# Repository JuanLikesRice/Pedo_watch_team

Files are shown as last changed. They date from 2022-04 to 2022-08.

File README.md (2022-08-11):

# Pedo_watch_team
Final for Elec327 code for MSP430

Website explaining our Design: https://olr148.wixsite.com/pedowatchteam/

DataSHeets for the pedometer sensor:
https://download.mikroe.com/documents/datasheets/KX126-1063.pdf
https://kionixfs.azureedge.net/en/document/AN073-Getting-Started-with-Pedometer.pdf

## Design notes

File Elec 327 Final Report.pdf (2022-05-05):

## Pedo-Watch: Final Project Written Report

By: Juan Garza, Son Nguyen, Oscar Reynozo

ELEC 327

Due: May 4, 2022

Professor Kemere

Design Concept:

We sought to design a simple energy-efficient electronic pedometer popularly used

among fitness and health enthusiasts. For our final project design, we introduce the Pedo-Watch.

Our watch utilizes the interrupt and SPI configuration capabilities of the MSP430G2553

microcontroller to detect and display the user’s number of steps. In addition, we incorporated a

pedometer three-click sensor to see the number of steps the person has taken and a color TFT

screen to display the time of the day and the number of steps that the user has taken.

Additionally, we implemented two-button functionality to be able to reset or set the step count

and current time.

Bill of Materials:

- Texas Instruments Launchpad
- 20-pin MSP430G2553
- Datasheet: https://elec327.github.io/assets/documents/msp430g2553.pdf
- Adafruit 1.14” 240x135 color screen with the ST7789VW TFT driver
- Link: https://www.adafruit.com/product/4383
- Datasheet:

https://cdn-learn.adafruit.com/assets/assets/000/082/882/original/ST7789VW_SP

EC_V1.0.pdf?1571860977

- Pedometer 3-Click Sensor
- Link: https://www.mikroe.com/pedometer-3-click
- Datasheet: https://download.mikroe.com/documents/datasheets/KX126-1063.pdf
- Two buttons
- Two 1k Ohm resistors
- 100k Ohm resistor
- 4.7k Ohm resistor
- Two 47nF capacitors
- Two 0.1uF capacitors

SPI Configuration:

Generally, our Pedo-Watch works by configuring the KX126-1063 IC, our pedometer

three-click sensor, and the Adafruit 1.14” 240x135 color screen with the ST7789VW TFT driver,

our color TFT display. We decided to use the SPI interface because our pedometer and screen

require a high-speed clock to check and update the number of steps taken and the current time.

For our SPI configuration, the MSP430G2553 serves as the master device. Meanwhile, the

screen and pedometer serve as slave devices. With the exception of the pedometer, each slave

device usually has a dedicated chip select pin connection to the MSP430G2553 to determine the

slave device that the MSP430G2553 is writing to at any given time. In this case, when providing

input or receiving an output from a device, the MOSI (Master-out, Slave-in) and MISO

(Master-in, Slave-out) configurations determine the direction in that information is being read or

written.

Pedometer Configuration and Implementation:

With the KX126-1063's SPI configuration, we utilized a 0.5 MHz clock signal to

determine whether to read or write at every positive edge of the clock signal. When given a read

or write command at every positive edge of the clock signal, the command must modify the IC's

registers to access settings specified by the chip's datasheet. The MSP430G2553 must first set

the pedometer to software reset mode, which requires control register one and control register 2

to be changed. Once in software reset, the sensor can be configured into a pedometer function

and count steps. The KX126-1063 IC can function as both a pedometer and an accelerometer.

Under the pedometer configuration mode, the acceleration register has access to ten different

control registers PED_CNTL_XX; these control how the pedometer counts steps, including the

threshold for calculating steps. In addition, there are two 8-bits registers used to represent the

step count, one register corresponding to the high values (8 most significant bits of steps) and

another register corresponding to the low values (8 least important bits of the step count). When

the displacement reaches a certain threshold where the sensor accelerates and decelerates from

the threshold value, a step is detected, and the step counter increments. In addition, there are

configurations for the interrupt pin; these can set pins to be active or low for when the pedometer

counts above a threshold of steps.

TFT Screen Configuration and Implementation:

Moreover, the TFT screen's SPI configuration works similarly to the KX126-1063's SPI

configuration. However, we configured it with a 1 MHz clock signal for writing or reading data

at the positive edge of each clock cycle. To set up the TFT screen, we must first initialize a

software reset, then configure the master, phase, and synchronous modes in the specified order

by sending commands specified in the datasheet and modifying the TFT screen's control

registers. Once the TFT screen can receive bytes for displaying text, the CASET and RASET

commands must be used to specify the row and column when drawing a pixel. The RAMWR

(for writing to the RAM) command writes its corresponding byte value to the UCB0TXIFG

buffer, and a byte indicates the pixel's color. Thus, to write messages to the screen, each pixel in

the screen must be iterated through and colored appropriately to form text on the screen with a

specific text font and color. Utilizing this framework for writing text onto the TFT screen, we

used a custom font for a microcontroller and itoa function in C to convert the current number of

steps and time from an integer to a string displayed onto the TFT screen as the values update.

Once the screen successfully updates the number of steps and time as part of our minimally

viable product, we incorporate animations with color changes and transitions to make the TFT

screen more appealing and entertaining. Unlike the step counter, the time counter continuously

incremented every second and timed appropriately using an interrupt delay.

Buttons Implementation and FSM:

The last component of the system implemented was the two buttons' active low

functionality. These buttons operate in a finite state machine. The initial state is displaying,

where the top button corresponds to reading the step registers and updating the count if there are

steps stored in the sensor. The bottom button corresponds to resetting the step count to zero.

When both buttons are pressed simultaneously, the TFT display is set to a time-setting state. The

top button increments the hour value of the current time, and pressing the bottom button minute

value of the current time. Conditionals in the code ensure that decreasing the time does not go

below 00:00 and increasing the time does not go above 23:59. Once in time-setting mode, the

user can leave the time-setting mode and set the time chosen by pressing both buttons at the

same time again. A state machine diagram is drawn below.

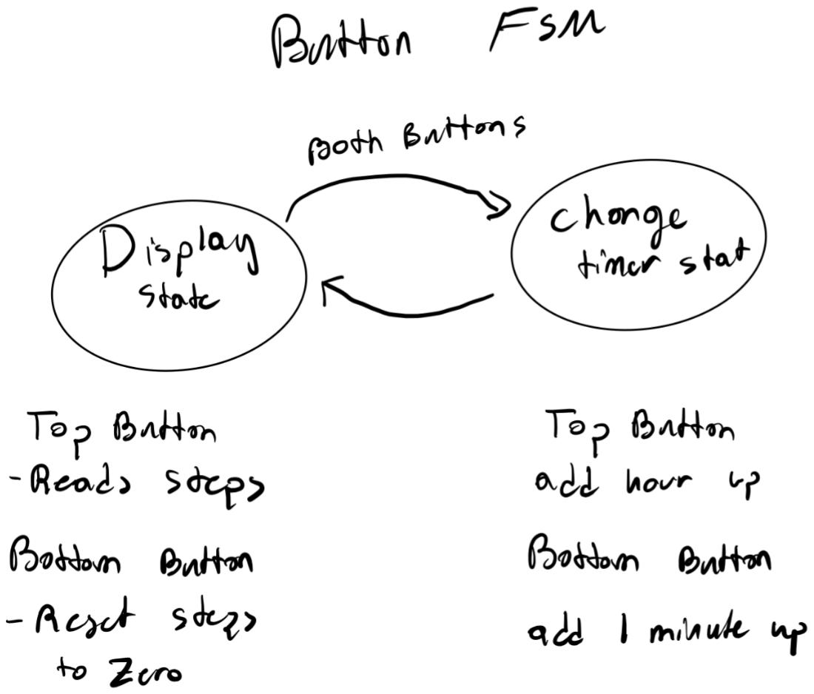
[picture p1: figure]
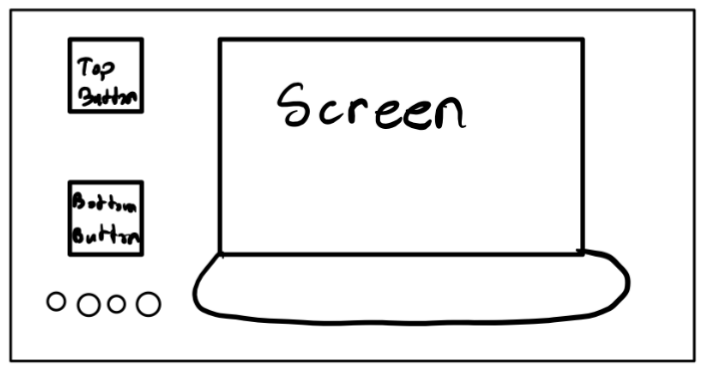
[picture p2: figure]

PCB Design:

For our PCB design, aside from including the MSP430G2553, the KX126-1063, the

display’s pins, and the buttons, we also had the 4-pins (GND, VDD, RST, and TEST) connecting

to the launchpad for uploading code and resistors/capacitors needed for some of the pedometer

and button connections. Here below are images of our Eagle PCB schematic and board files:

Eagle PCB Schematic File

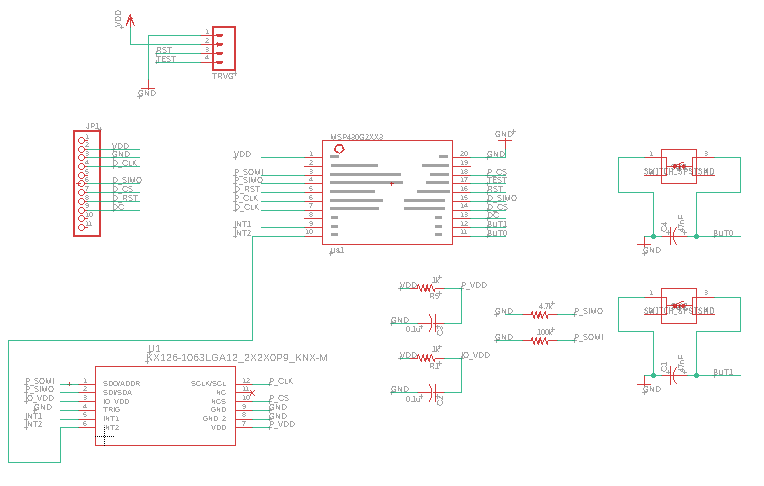
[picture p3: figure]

The 47 nF capacitors connected to the buttons eliminate noise and ensure a smooth

transition from high to low. Further, the 1k ohm resistor and 0.1 uF capacitor voltage dividers

supply 2.2 V to the KX126-1063 chip. Lastly, the 4.7k ohm and 100k ohm resistors reduce the

noise in the data transmitted from SDO and SDI pins in the KX126-1063 chip.

Eagle PCB Board File

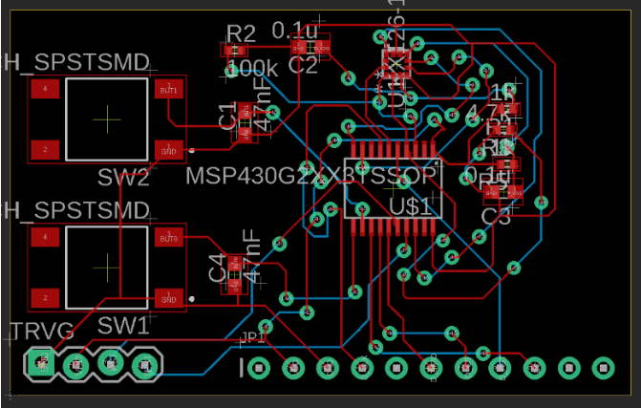
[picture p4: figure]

Only the DVCC and DVSS pins of the microcontroller are shared among the different

components of the PCB to supply voltage and ground. Except for the vacant pins P1.0, P2.0, and

P2.6, the rest of the microcontroller’s pins are allocated to a specific purpose for a single

component. Lastly, for reference, here are the pin layouts for the 20-pin MSP430G2553

microcontroller and KX126-1063 IC, along with each pin’s use:

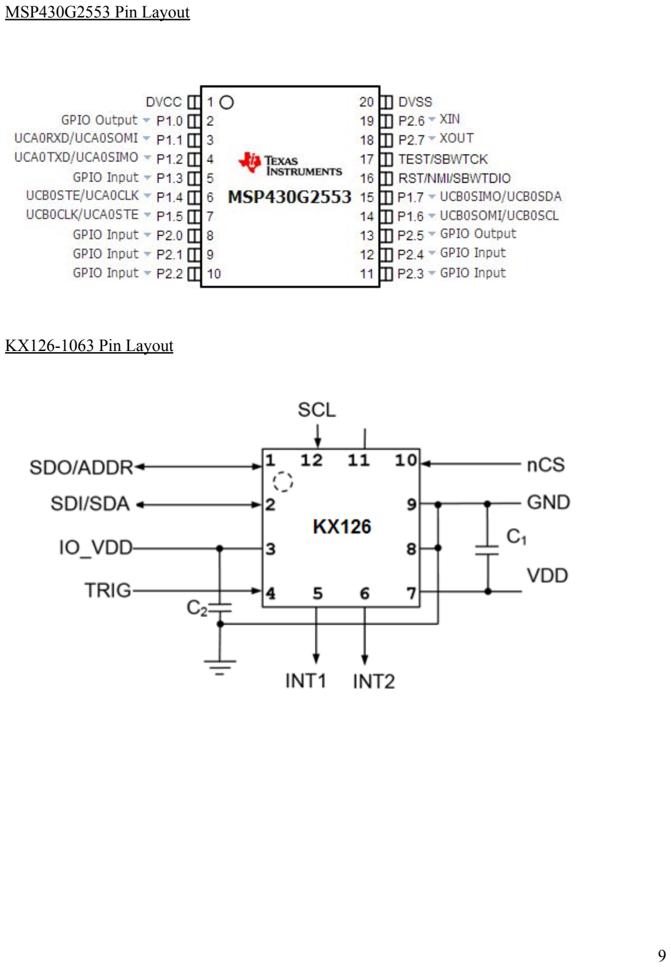
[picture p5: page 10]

MSP430G2553 Pin Layout

KX126-1063 Pin Layout

Low-Power Implementation:

We achieved our goal of making the Pedo-Watch a low-power system by extensively

utilizing interrupts throughout our system when awaiting inputs or information to be read,

written, or transmitted. Instead of the delay cycles function that keeps the MSP430G2553 on

while awaiting a delay, we created a delay function that configures the appropriate CCR0

interrupt settings that puts the MSP430G2553 to sleep wakes up the MSP430G2553 using the

LPM3 bits. Additionally, we employ the active low button interrupt to update the number of

steps displayed on the screen after the user’s every twelve steps to increase the pedometer’s

efficiency when updating the step count. Further, utilizing the interrupt for delays reduces the

time that the MSP430G2553 is left powered on, reducing the amount of power it consumes.

Challenges:

Our main challenge throughout developing the Pedo-Watch was being able to send bytes

to our pedometer and screen given the lack of available C libraries and sample code for

interfacing our components with the MSP420G2553. However, we “reverse engineered” the

commands needed to send information to each device. To achieve this, we found a sample

working Arduino code for both the screen and the pedometer, where we uploaded the code to an

Arduino and probed the MISO and SCLK pins of each component to read the bytes of each

command transmitted. Each byte’s equivalent hexadecimal value had a corresponding command

in the datasheet. Once the MSP430G2553 writes the correct commands to each component, the

MSP430G2553 can successfully write data to each component. Additionally, we experienced

significant difficulties with finding the right timing for reading signals from the KX126 Sensor,

we were one read buffer behind which caused initial confusion.

Team Member Contributions:

Juan Garza:

- Wrote hardware configuration for the pedometer and implemented functions to initialize

the pedometer and detect steps with user motion

- Implemented button functionality with resetting the time/step count and setting time

depending on buttons pressed

- Soldered final PCB

Son Nguyen:

- Worked on “reverse engineering” screen configuration by probing screen and running

sample Arduino code while finding corresponding commands in the screen’s datasheet.

- Developed 1st PCB
- Wrote hardware configuration for the screen as well as implemented functions to

initialize the display and send bytes, color, and draw pixels to the display.

- Integrated both pedometer and screen functionalities to run simultaneously
- Assisted in soldering final PCB

Oscar Reynozo:

- Worked on “reverse engineering” screen configuration by probing screen and running

sample Arduino code while finding corresponding commands in the screen’s datasheet.

- Significantly researched and wrote notes for the team on the SPI interface for the

MSP430G2553

- Developed 2nd and Final PCB

- Wrote written report, slides for presentation, website, and recorded/edited presentation

videos

- Wrote code for text fonts and functions for writing letters and strings of text to the screen
- Assisted in soldering final PCB

Final Project Presentation Link: https://www.youtube.com/watch?v=Jgsx6iXTma4&t=416s

Final Project Demonstration Link: https://www.youtube.com/watch?v=IDnrIIwVhfU

Github Link (includes code and PCB files):

https://github.com/JuanLikesRice/Pedo_watch_team

Sources:

- Fonts for microcontrollers:

https://jared.geek.nz/2014/jan/custom-fonts-for-microcontrollers

- Adafruit 1.14” 240x135 TFT LCD Display Arduino Sample Code:

https://learn.adafruit.com/adafruit-1-14-240x135-color-tft-breakout/arduino-wiring-test

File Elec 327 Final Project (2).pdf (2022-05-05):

# Pedo-Watch: Elec 327 Final Project

By: Juan Garza, Son Nguyen, Oscar Reynozo

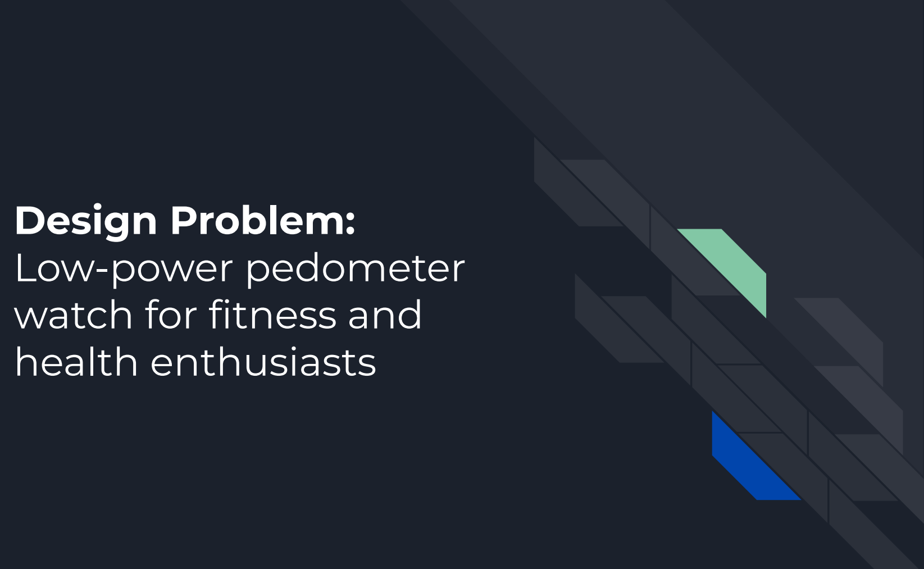
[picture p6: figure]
Design Problem: Low-power pedometer watch for fitness and health enthusiasts

## Design Concept:

- Energy-efficient
pedometer
- Displays time (military) and number of steps via
color TFT screen
- Button functionality to
set/reset time and step

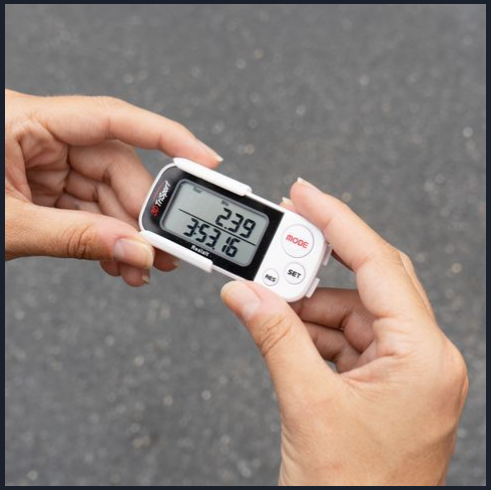
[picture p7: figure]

count | Source:
| https://www.verywellfit.com/realalt-3dtri sport-walking-3d-pedometer-review-47
| 82140

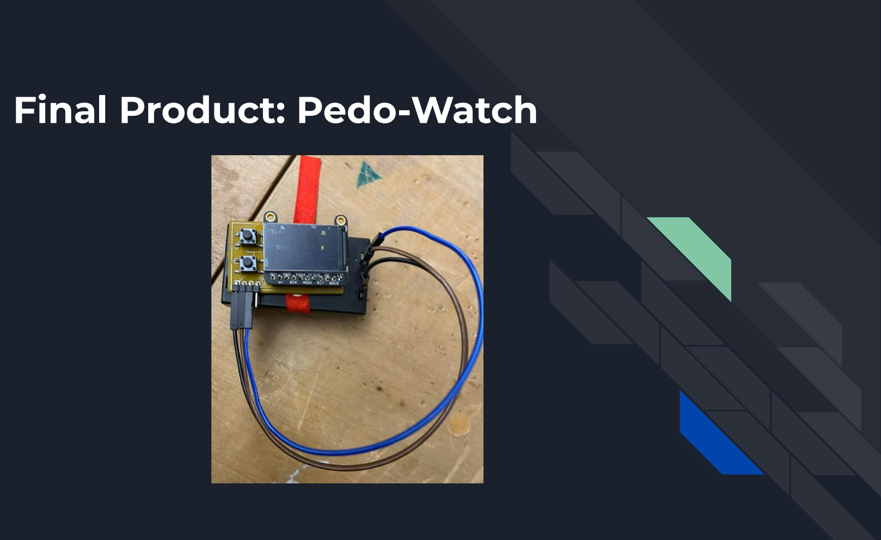
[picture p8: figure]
Final Product: Pedo-Watch

## Materials

- Texas Instruments
Launchpad
- 20-pin MSP430G2553
- Adafruit 1.14” 240 x
135 pixel screen
- KX126-1063 IC
- Two buttons
- Two 1k Ohm resistors
- 4.7k Ohm resistor
- 100k Ohm resistor
- Two 47 nF capacitors
- Two 0.1uF capacitors

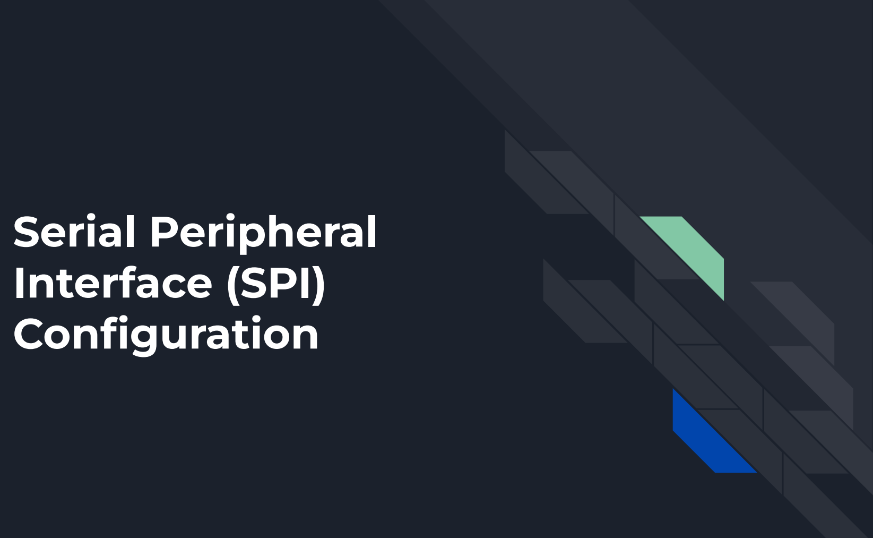
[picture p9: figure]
Serial Peripheral Interface (SPI) Configuration

### Serial Peripheral Interface (SPI) Configuration

- Serial communication
interface chosen due to
high clock speed needed
for updating step
count/time
- Master Device:
MSP430G2553
- Slave Devices:
- Pedometer
- Screen

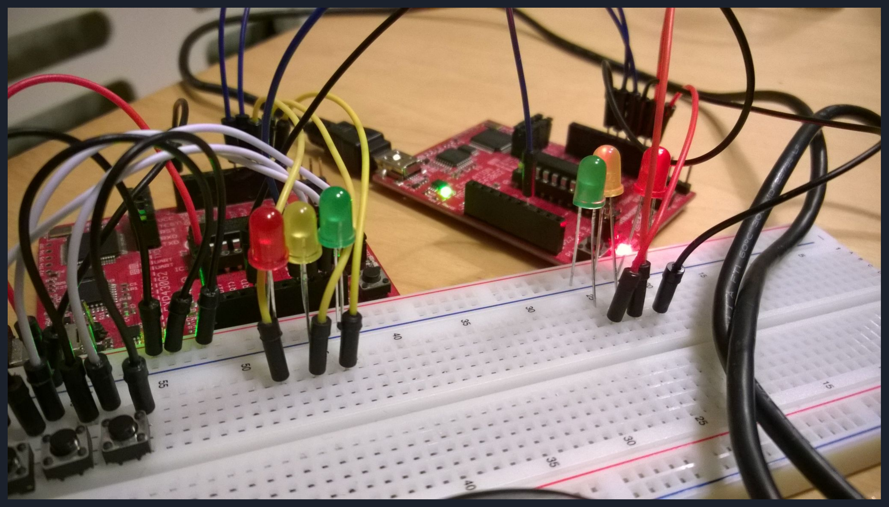
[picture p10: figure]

Source:
https://www.tns-labs.org/msp430-spi-communication/

## SPI Configuration (Continued)

- Chip Select (CS) pin
determines slave device that the master device writes
information to
- MISO (Master-in, Slave-out) and MOSI (Master-out,
Slave-in) configurations
determine direction of
information transmission

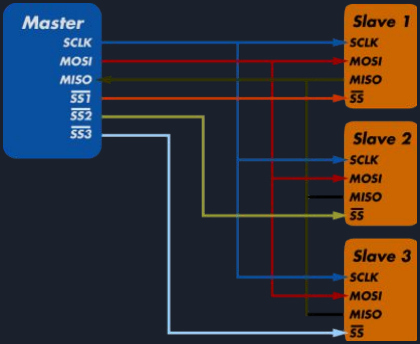
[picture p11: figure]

Source:
https://www.totalphase.com/blog/2020/07/wh at-is-spi-protocol-how-to-debug-spi-communic ation/

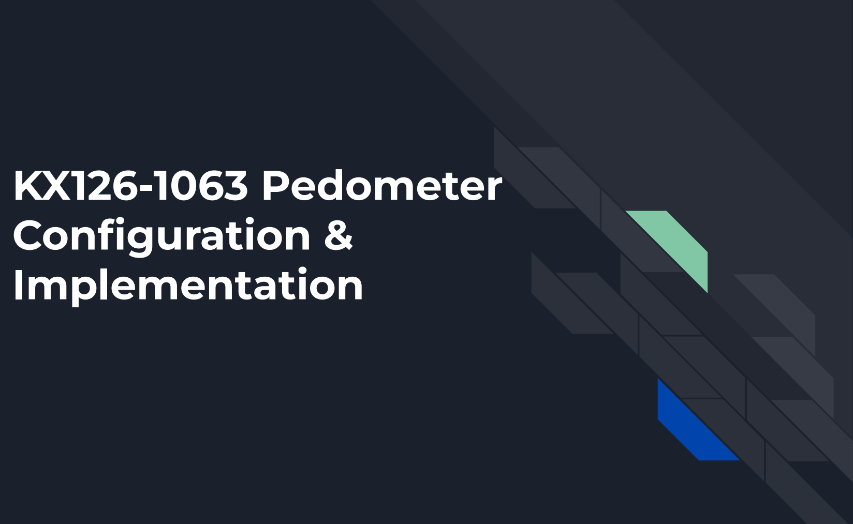
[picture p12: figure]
KX126-1063 Pedometer Configuration & Implementation

## Pedometer Configuration

- Chip: KX126-1063 IC
- Clock Speed: 0.5 MHz
- Write: send two bytes - address and value for address
- Read - Send two bytes - address and dummy variable to provide clock
- Initial Software Reset
- Set pedometer configuration mode
- Adjust step threshold control register

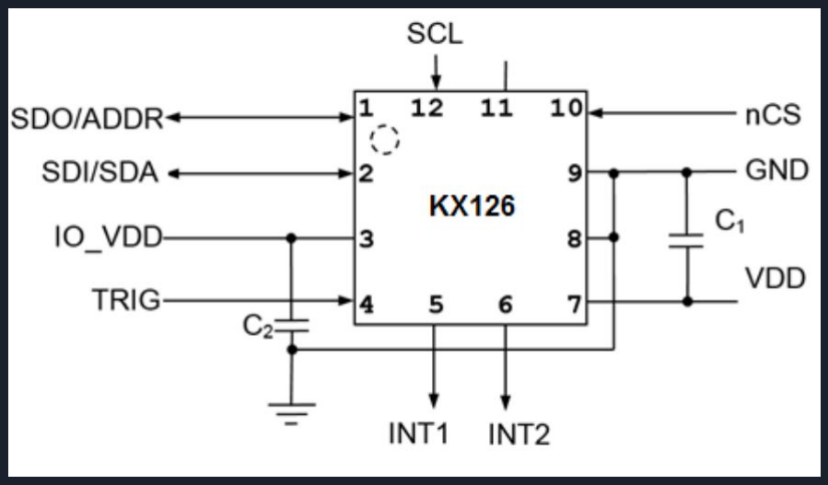
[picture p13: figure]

Source:
https://download.mikroe.com/documents/datasheets/KX126-1063.pdf

### Pedometer Implementation

- Two 8-bit displacement
registers
- Interrupt Pin 2 – GPIO 2.2 -automatically adds steps
- Interrupt updates steps
displayed after every 12
steps

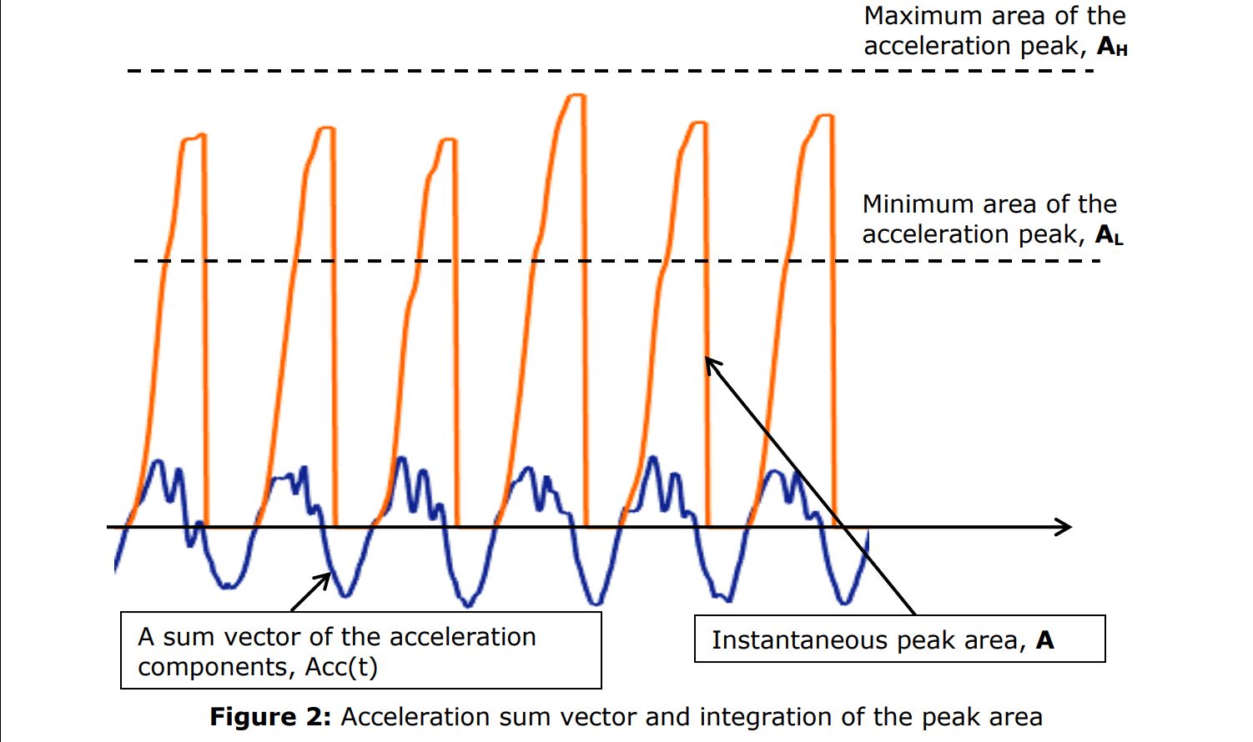
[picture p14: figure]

Source:
https://www.researchgate.net/figure/Displ acement-velocity-and-acceleration-for-a-c am-with-a-constant-velocity-profile-for_fi g2_337140375

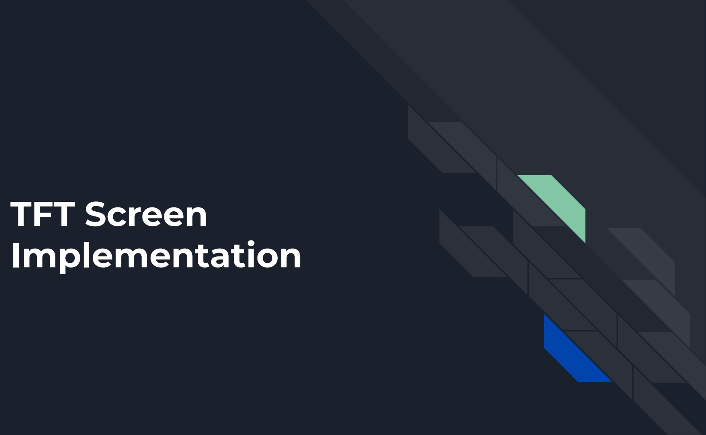
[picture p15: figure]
TFT Screen Implementation

## TFT Screen Configuration

- Chip: ST7789VW
- Clock Speed: 8 MHz
- Initialize software reset
- Configure master, phase, and asynchronous modes
to enable SPI
- CASET/RASET commands
specify row/column for

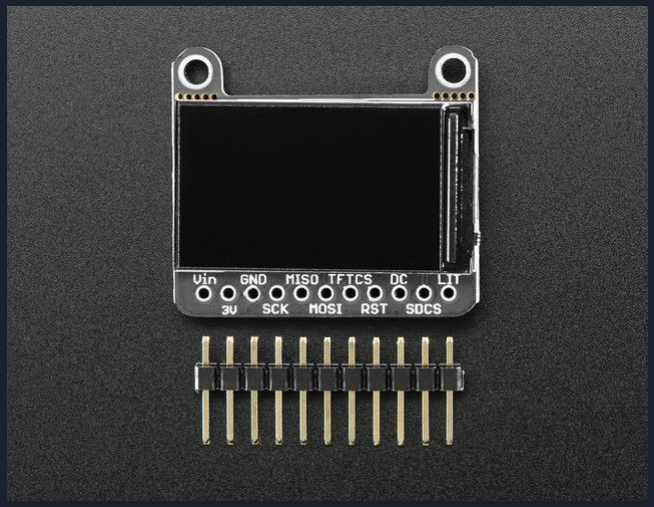
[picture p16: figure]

pixel drawn | Source:
| https://learn.adafruit.com/adafruit-1-14- 240x135-color-tft-breakout/pinouts

## TFT Screen Implementation

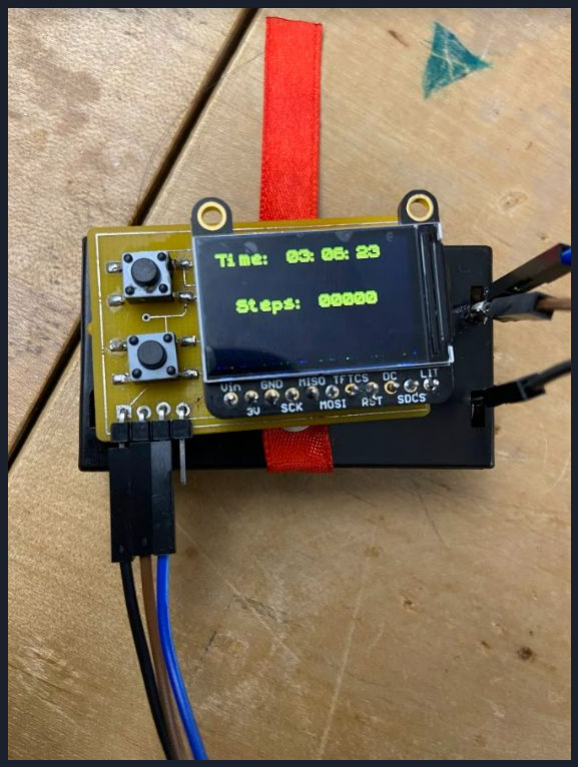
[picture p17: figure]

- Write byte to transmission buffer UCB0TXIFG
- Draw pixel with color
specified by byte
- Iterate drawing color pixels to draw text including step counter and time

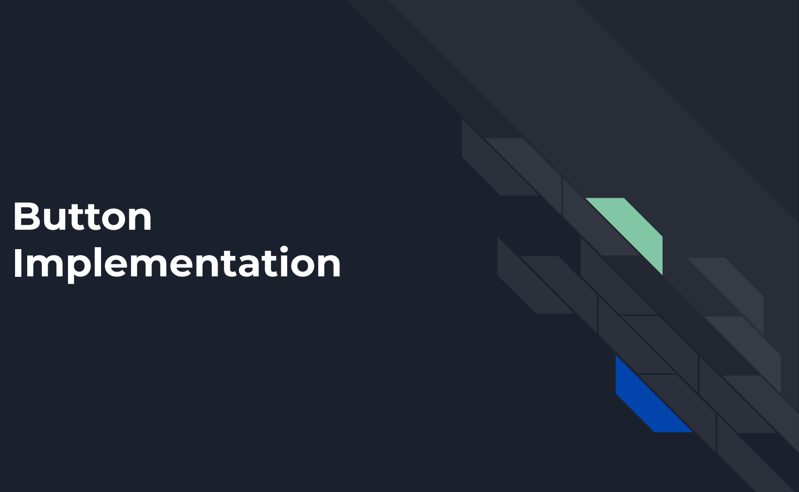
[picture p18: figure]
Button Implementation

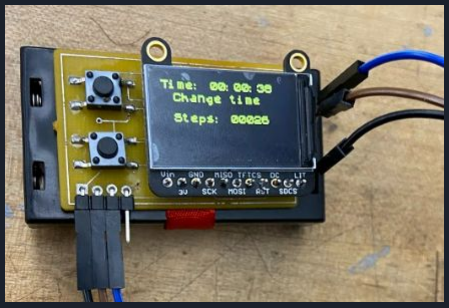
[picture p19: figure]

## Button Implementation

- Have a FSM for button function
- Having two buttons, top and bottom button
- State 1: Displaying
- Top button reads steps
- Bottom button reset steps to 0
- Press both to change state to change time
- State 2: Change Time
- Top button changes hours
- Bottom button changes minutes
- Press both to change state to displaying

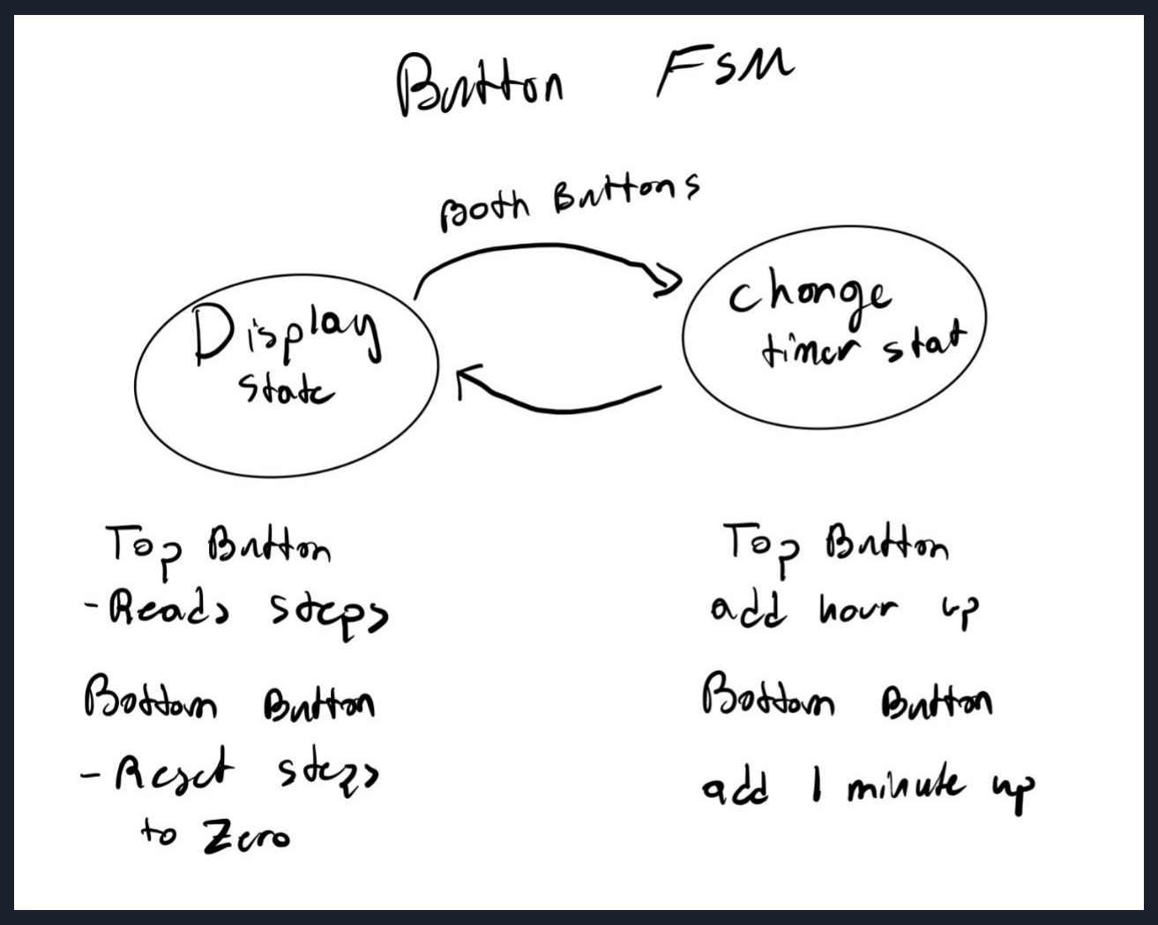
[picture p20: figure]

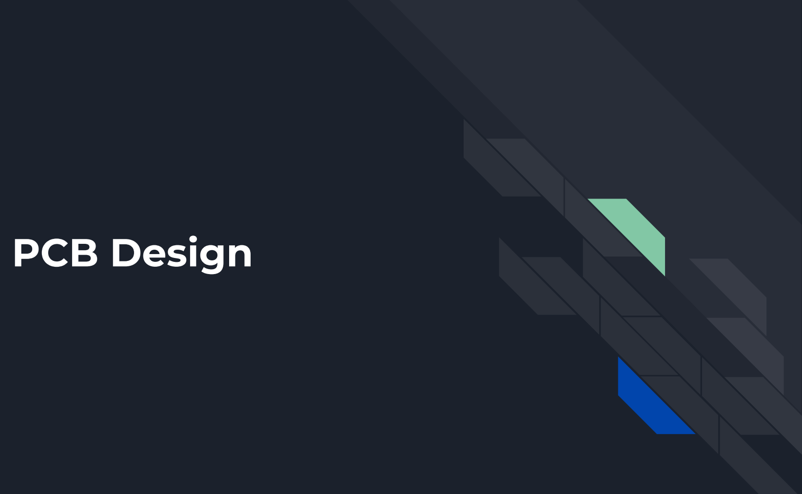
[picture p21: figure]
PCB Design

# PCB Layout

- Other components:
- 4 pins connecting
Launchpad
- Resistors/capacitors
for pedometer and
button connections
- Only DVCC/DVSS pins
shared
- Vacant pins: P1.0, P2.0, P2.6
- Remaining pins
allocated to certain
purpose for a specific
component

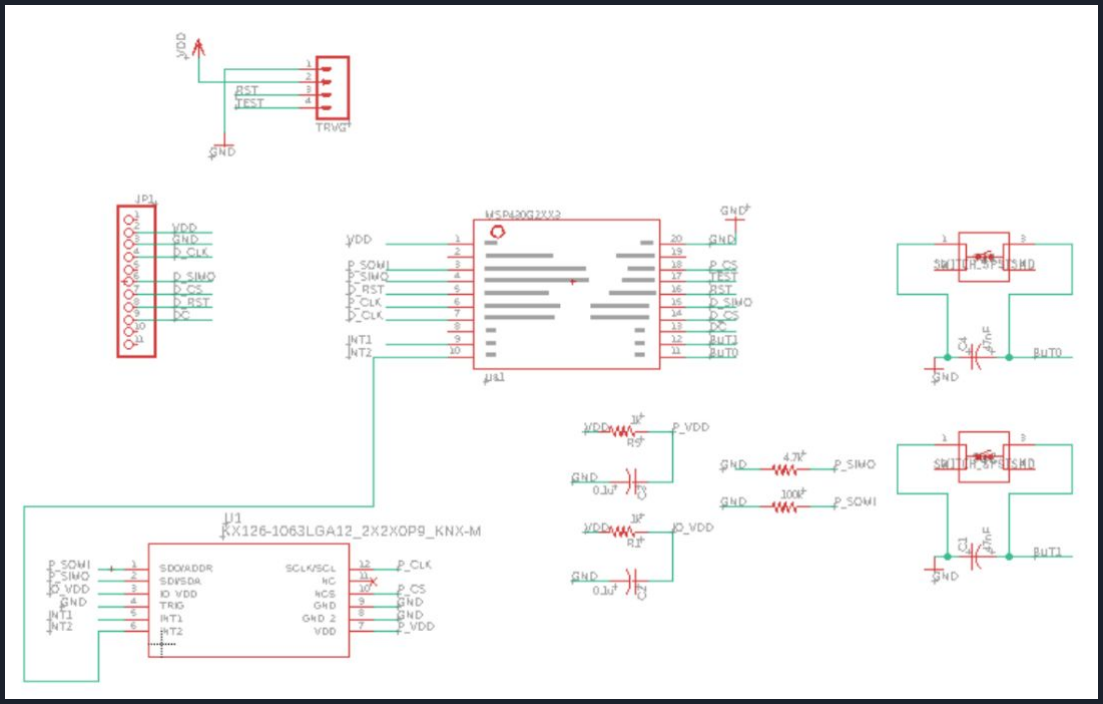
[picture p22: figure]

PCB Eagle Schematic

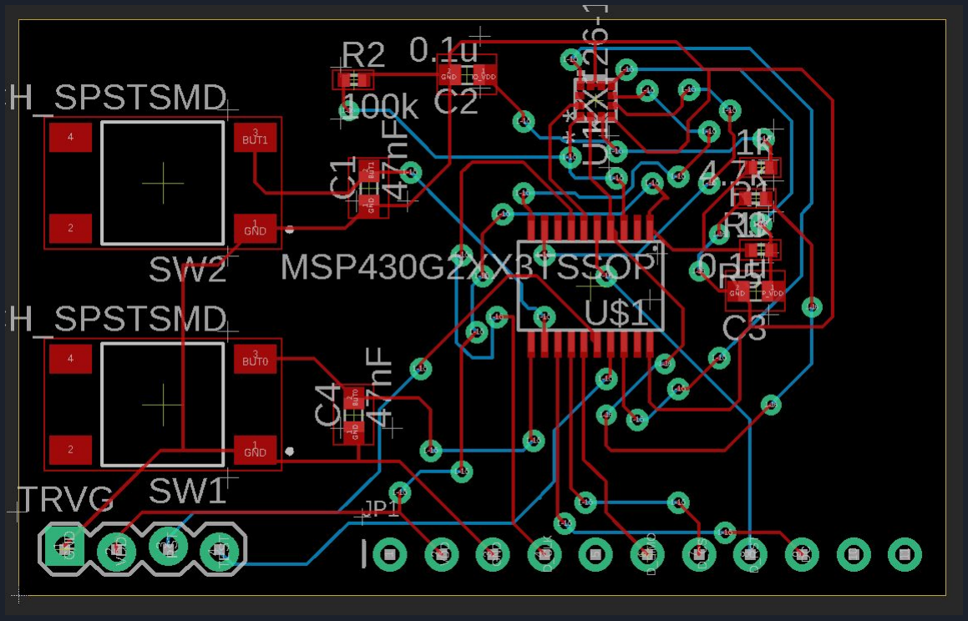
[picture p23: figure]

PCB Eagle Board

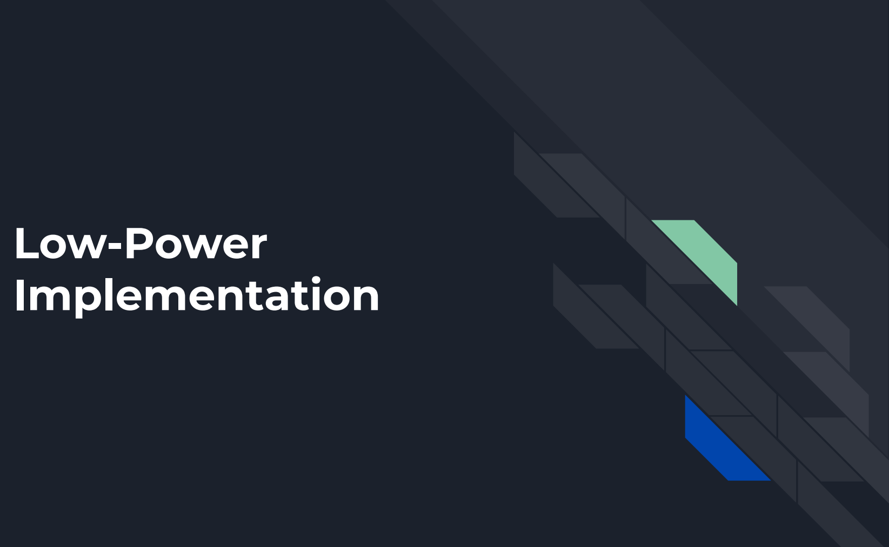
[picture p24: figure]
Low-Power Implementation

## Low-Power Implementation

- Use interrupts for
delaying tasks
- delay() function uses
CCR0 interrupt to put
MSP430 to sleep
awaiting an input time
- Active low button
interrupt updates step
count displayed after


each 12 steps | Source: http://www.ocfreaks.com/msp43 0-timer-programming-tutorial/

Challenges

## Challenges

- Initial difficulties interfacing with pedometer and screen
- “Reverse engineer”
commands via running
sample code and probe
with oscilloscope
- Correct timing with
writing to transmission
buffer


Source:
https://searchengineland.com/reverse -engineer-online-advertising-strategy-288994

Takeaways

## Takeaways

- Heavily-utilize interrupts when prioritizing low-power consumption
- Datasheets and “Reverse engineering” devices are very effective for understanding devices’ functionality
- Run sample code and probe to find necessary commands

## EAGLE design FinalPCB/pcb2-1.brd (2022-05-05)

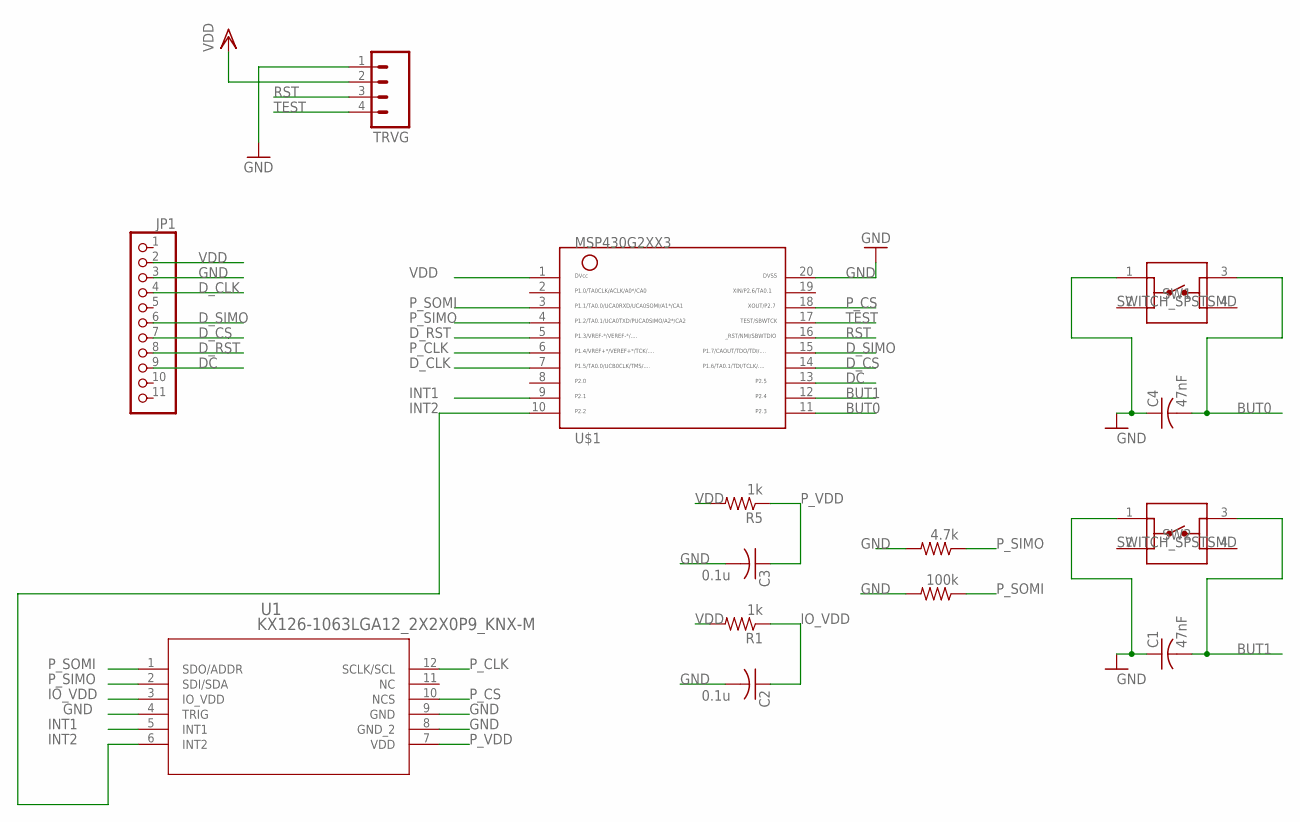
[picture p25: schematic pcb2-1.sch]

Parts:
C1, C4: 47nF; C0603
C2, C3: 0.1u; C0603
JP1: HEADER-1X11; 1X11_ROUND
R1, R5: 1k; R0402
R2: 100k; R0402
R3: 4.7k; R0402
SW1, SW2: SWITCH_SPSTSMD; SW_1571563-4
TRVG: M04LOCK; 1X04_LOCK
U1: KX126-1063LGA12_2X2X0P9_KNX-M; LGA12_2X2X0P9_KNX-M
U$1: MSP430G2XX3TSSOP; PW20

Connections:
BUT0: C4.2, SW1.3, U$1.11
BUT1: C1.2, SW2.3, U$1.12
DC: JP1.9, U$1.13
D_CLK: JP1.4, U$1.7
D_CS: JP1.7, U$1.14
D_RST: JP1.8, U$1.5
D_SIMO: JP1.6, U$1.15
GND: C1.1, C2.2, C3.2, C4.1, JP1.3, R2.2, R3.2, SW1.1, SW2.1, TRVG.1, U1.4 (TRIG), U1.8 (GND_2), U1.9 (GND), U$1.20
INT1: U1.5 (INT1), U$1.9
INT2: U1.6 (INT2), U$1.10
IO_VDD: C2.1, R1.1, U1.3 (IO_VDD)
P_CLK: U1.12 (SCLK/SCL), U$1.6
P_CS: U1.10 (NCS), U$1.18
P_SIMO: R3.1, U1.2 (SDI/SDA), U$1.4
P_SOMI: R2.1, U1.1 (SDO/ADDR), U$1.3
P_VDD: C3.1, R5.1, U1.7 (VDD)
RST: TRVG.3, U$1.16
TEST: TRVG.4, U$1.17
VDD: JP1.2, R1.2, R5.2, TRVG.2, U$1.1

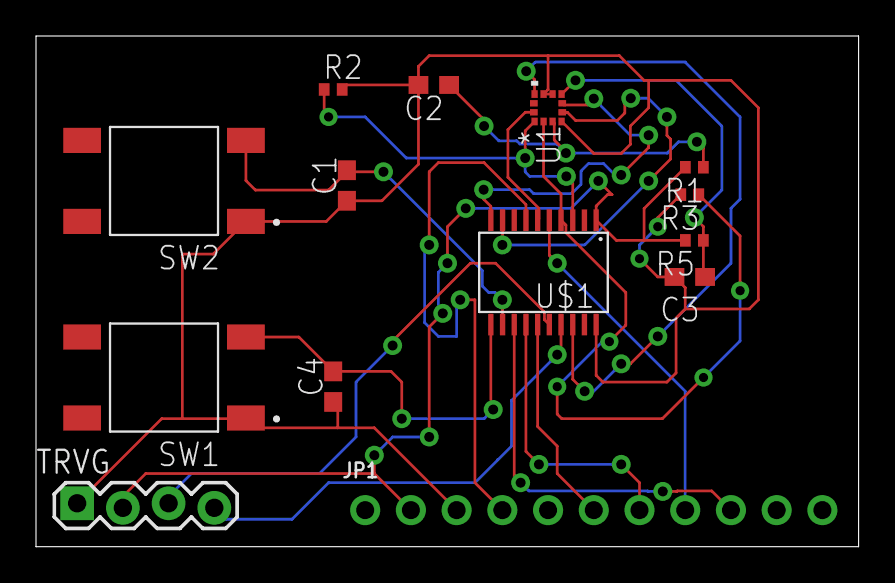
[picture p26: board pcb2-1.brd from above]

Board: 2 copper layers, 45.7 x 28.4 mm, 14 parts (0 on the bottom side), 19 nets.

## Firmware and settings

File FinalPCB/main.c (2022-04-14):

#include <msp430.h>
#include <stdint.h>
#include <stdio.h>


void delay_setup(){
      WDTCTL = WDTPW + WDTHOLD;                 // Stop WDT
      P1DIR |= 0x01;                            // P1.0 output
      CCTL0 = CCIE;                             // CCR0 interrupt enabled
      CCR0 = 31250;                             // first time when interupts turns off
      TACTL = TASSEL_2 + MC_2 + ID_3;           // SMCLK, contmode
}
void delay(unsigned int time){
    //unsigned int timer;
    //for (timer=0;timer<time; timer++){
    CCR0 += time;
    __bis_SR_register(LPM0_bits + GIE);
    CCR0 += time;
}

void spi_setup(void)
{
    WDTCTL = WDTPW + WDTHOLD; // Stop WDT
    UCB0CTL1 |= UCSWRST;      // Enable SPI software rezet
    UCB0CTL1 |= UCSSEL_2;     // SMCLK clock
    UCB0CTL0 |= UCSYNC;       //spi mode
    UCB0CTL0 |= UCMODE_1;     //master
    UCB0CTL0 |= UCMST;        //master
    UCB0CTL0 |= UCMSB;        //MSB


    UCB0BR0  |= 0x01; // /2 --> 1MGhz OD THE SPI CLOCK
   //UCA0CTL0 |= UCCKPH + UCMSB + UCMODE_1; // 4-pin, 8-bit SPI master
   //UCA0CTL0 |= UCCKPH + UCMSB + UCMST + UCSYNC; // 3-pin, 8-bit SPI master
    //UCA0BR1 = 0; //
    //UCA0MCTL = 0; // No modulation
    UCB0CTL1 &= ~UCSWRST; // **Initialize USCI state machine**

    P1SEL  |= BIT7;                                 // Just setup for the pins (1.7 is the D_SIMO)
    P1SEL2 |= BIT7;
//    P1SEL  |= BIT2;                               // Just setup for the pins (1.2 is the SIMO data line)
//    P1SEL2 |= BIT2;
    P1SEL  |= BIT5;                                 //Just setup for the pins (1.5 is the D_CLK)
    P1SEL2 |= BIT5;
    P1DIR  |= BIT4;                                 // chip select for display
    P1OUT  |= (BIT4);                               // VDD - on

    P2DIR  |= BIT5;                                 // chip select for display
    P2OUT  &= ~(BIT5);                              //Set Command

    P1DIR |= BIT0; //ReSet Pin
}

//4-line serial interface II
void write1byte( uint8_t *message){
//    P1OUT &= ~(BIT4);
//    UCB0TXBUF= message[0]; ///address
//    P1OUT |= (BIT4);
//    while (!(IFG2 & UCB0TXIFG));
//    P1OUT &= ~(BIT4);
////    while (!(IFG2 & UCB0TXIFG));
//    UCB0TXBUF=  message[1]; //value
//    P1OUT |= (BIT4);
//    while (!(IFG2 & UCB0TXIFG));
//    P1OUT &= ~(BIT4);
////    while (!(IFG2 & UCB0TXIFG));
//    P1OUT |= (BIT4); //Turn on
    int i = 0, o =0;
    for(;o<135;o++){
        for(;i<180; i++){
            UCB0TXBUF= message[0]; ///address
            UCB0TXBUF= message[1]; ///address
        };
    };
}

void commandSetup(int8_t *message){
    int i=0;
    while(message[i] != NULL){
        UCB0TXBUF= message[0];
        i++;
    }
}

uint8_t color[] = {0xF1,0xF2}; // 1111 001 1111 0010
uint8_t color2[] = {0x00,0x00};
uint8_t SPI2EN[] = {0x00,0xE7};
uint8_t SPI2ENCON[] = {0x00,0x00};

uint8_t SWRESET[] = {0x00,0x01,NULL}; //Software Reset - 163
uint8_t SLPIN[] = {0x00,0x10,NULL};   //Sleep in - 182
uint8_t SLPOUT[] = {0x00,0x11,NULL};  //Sleep out - 184

uint8_t COLMOD[] = {0x00,0x3A,0x00,0x03,NULL}; //COLMOD


int main(void)
{
    spi_setup();
    delay_setup();

    P1OUT &= (~BIT0); //Reseting
    delay(10000);
    P1OUT |= BIT0; //Set Reset to high

    P1OUT &= (~BIT4);                //Turn off Chip select to enable transmission.
    P2OUT  &= ~(BIT5);               //Set COMMAND
    write1byte(SPI2EN);
    P2OUT  |= (BIT5);                //Set DATA
    write1byte(SPI2ENCON);
    P1OUT |= (BIT4);                // Turn on chip select to disable transmission.

    P1OUT &= (~BIT4);                //Turn off Chip select to enable transmission.
    P2OUT  &= ~(BIT5);               //Set COMMAND
    write1byte(SPI2EN);
    P2OUT  |= (BIT5);                //Set DATA
    write1byte(SPI2ENCON);
    P1OUT |= (BIT4);                // Turn on chip select to disable transmission.


    while(1)
    {

        P2OUT  |= (BIT5);                              //Set DATA
        int i = 0, o =0;
        P1OUT &= (~BIT4);                               //Turn off Chip select to enable transmission.
        write1byte(color);
        P1OUT |= (BIT4);                                // Turn chip select on.
        for(i=0;i<10;i++)
            delay(10000);
    }
}




// Timer A0 interrupt service routine
#if defined(__TI_COMPILER_VERSION__) || defined(__IAR_SYSTEMS_ICC__)
#pragma vector=TIMER0_A0_VECTOR
__interrupt void Timer_A (void)
#elif defined(__GNUC__)
void __attribute__ ((interrupt(TIMER0_A0_VECTOR))) Timer_A (void)
#else
#error Compiler not supported!
#endif
{
  __bic_SR_register_on_exit(LPM0_bits);
}

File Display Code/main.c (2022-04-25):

#include <msp430.h>
#include <stdint.h>
#include <stdio.h>
#include <stdbool.h>

//Define some common commands.
#define SWRESET 0x01 //Software Reset - 163
#define SLPIN 0x10   //Sleep in - 182
#define SLPOUT 0x11  //Sleep out - 184
#define PTLON 0x12   //Partial Display Mode On - 186
#define NORON 0x13   //Normal Display Mode On - 187
#define INVOFF 0x20   //Display Inversion Off  - 188
#define INVON 0x21     //Display Inversion On  - 188
#define DISPOFF 0x28   //Display Off  - 194
#define DISPON 0x29   //Display On  - 196
#define CASET 0x2A //Column Address Set - 198
#define RASET 0x2B //Row Address Set - 200
#define RAMWR 0x2C // Memory Write - 202
#define MADCTL 0x36 //Memory Data Access Control  - 215
#define COLMOD 0x3A //Interface Pixel Format - 224
#define WRDISBV 0x51 //Write Display Brightness - 233
#define WRCTRLD 0x53 //Write CTRL Display - 237
#define WRCACE 0x55 //Write Content Adaptive Brightness Control and Color Enhancement - 241
#define WRCABCMB 0x5E //Write CABC Minimum Brightness -245

#define CHAR_WIDTH 6
#define CHAR_HEIGHT 8

//Define some common colors
#define WHITE 0xFFFF
#define YELLOW 0xFFE0
#define MAGENTA 0xF81F
#define RED 0xF800
#define CYAN 0x07FF
#define GREEN 0x07E0
#define BLUE 0x001F
#define BLACK 0x0000

const unsigned char font[96][6] = {
    {0x00,0x00,0x00,0x00,0x00,0x00}, //
    {0x2f,0x00,0x00,0x00,0x00,0x00}, // !
    {0x03,0x00,0x03,0x00,0x00,0x00}, // "
    {0x12,0x3f,0x12,0x12,0x3f,0x12}, // #
    {0x2e,0x2a,0x7f,0x2a,0x3a,0x00}, // $
    {0x23,0x13,0x08,0x04,0x32,0x31}, // %
    {0x10,0x2a,0x25,0x2a,0x10,0x20}, // &
    {0x02,0x01,0x00,0x00,0x00,0x00}, // '
    {0x1e,0x21,0x00,0x00,0x00,0x00}, // (
    {0x21,0x1e,0x00,0x00,0x00,0x00}, // )
    {0x08,0x2a,0x1c,0x2a,0x08,0x08}, // *
    {0x08,0x08,0x3e,0x08,0x08,0x08}, // +
    {0x80,0x60,0x00,0x00,0x00,0x00}, // ,
    {0x08,0x08,0x08,0x08,0x08,0x00}, // -
    {0x30,0x30,0x00,0x00,0x00,0x00}, // .
    {0x20,0x10,0x08,0x04,0x02,0x00}, // /
    {0x1e,0x31,0x29,0x25,0x23,0x1e}, // 0
    {0x22,0x21,0x3f,0x20,0x20,0x20}, // 1
    {0x32,0x29,0x29,0x29,0x29,0x26}, // 2
    {0x12,0x21,0x21,0x25,0x25,0x1a}, // 3
    {0x18,0x14,0x12,0x3f,0x10,0x10}, // 4
    {0x17,0x25,0x25,0x25,0x25,0x19}, // 5
    {0x1e,0x25,0x25,0x25,0x25,0x18}, // 6
    {0x01,0x01,0x31,0x09,0x05,0x03}, // 7
    {0x1a,0x25,0x25,0x25,0x25,0x1a}, // 8
    {0x06,0x29,0x29,0x29,0x29,0x1e}, // 9
    {0x24,0x00,0x00,0x00,0x00,0x00}, // :
    {0x80,0x64,0x00,0x00,0x00,0x00}, // ;
    {0x08,0x14,0x22,0x00,0x00,0x00}, // <
    {0x14,0x14,0x14,0x14,0x14,0x00}, // =
    {0x22,0x14,0x08,0x00,0x00,0x00}, // >
    {0x02,0x01,0x01,0x29,0x05,0x02}, // ?
    {0x1e,0x21,0x2d,0x2b,0x2d,0x0e}, // @
    {0x3e,0x09,0x09,0x09,0x09,0x3e}, // A
    {0x3f,0x25,0x25,0x25,0x25,0x1a}, // B
    {0x1e,0x21,0x21,0x21,0x21,0x12}, // C
    {0x3f,0x21,0x21,0x21,0x12,0x0c}, // D
    {0x3f,0x25,0x25,0x25,0x25,0x21}, // E
    {0x3f,0x05,0x05,0x05,0x05,0x01}, // F
    {0x1e,0x21,0x21,0x21,0x29,0x1a}, // G
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
};

/**
 * This set up the delay using CCTL.
 */
void delay_setup(){
      WDTCTL = WDTPW + WDTHOLD;                 // Stop WDT
      BCSCTL1 |= CALBC1_8MHZ;
      DCOCTL |= CALDCO_8MHZ;
      BCSCTL3 |= LFXT1S_2;                      // ACLK = VLO
      CCTL0 = CCIE;                             // CCR0 interrupt enabled
      TACTL = TASSEL_1 + MC_2;                  // ACLK, Continuous mode => 12kHz
      CCR0 = 1;                                 // first time when interupts turns off
      CCTL0 &= ~CCIE;                           // CCR0 disable
}

/**
 * This delays the operation by time amount;
 * 12000kHz is 1 second
 */
void delay(unsigned int time){
    CCTL0 |= CCIE;                             // CCR0 enable
    CCR0 = TA0R+ time;
    __bis_SR_register(LPM3_bits + GIE);
    CCTL0 &= ~CCIE;                             // CCR0 disable
}

void display_spi_setup(void)
{
    //Set up SPI_B0 - 445
    UCB0CTL1 |= UCSWRST;      // Put B into software reset
    UCB0CTL1 |= UCSSEL_2;     // SMCLK clock = 1MGHz
    UCB0BR0  = 0;             // Set prescalar to 1 to get 1MGhz
    UCB0BR1 = 0;

    UCB0CTL0 |= UCMSB;        //Most Significant Bit first
    UCB0CTL0 |= UCMST;        //Master mode selected
    UCB0CTL0 |= UCCKPH;       //Phase mode.
    UCB0CTL0 |= UCMODE_1;     //4 pin SPI with UCxSTE active high; slave enabled when STE = 1;
    UCB0CTL0 |= UCSYNC;       //Synchronous mode enabled

    //--Configuring the ports
    //MOSI Configured
    P1SEL  |= BIT7;
    P1SEL2 |= BIT7;
    //D_CLOCK Configured
    P1SEL  |= BIT5;
    P1SEL2 |= BIT5;
    //Chip select for the display
//    P1SEL  |= BIT4;
//    P1SEL2 |= BIT4;
    P1DIR  |= BIT6;
    P1OUT |= BIT6; //chip select high (disable chip)

    UCB0CTL1 &= ~UCSWRST; // Take out of Software Reset

    //--Enable IRQs;
//    UC0IE |= UCB0TXIE;    //USCI_B0 transmit interupt enable
//    UC0IFG &= ~UCB0TXIFG; //clear USCI_B0 Transmit interrupt flag

    //COMMAND OR DATA GPIO
    P2DIR  |= BIT5;
    P2OUT  &= ~(BIT5); //Set to Command Initially

    //Reset Display
    P1DIR |= BIT3;
    P1OUT |= BIT3;

    //LED Indicator
    P2DIR  |= BIT1;
    P2OUT  &= ~(BIT1);

    //BUTTON SWITCHES;
    P2DIR &= ~(BIT3 | BIT4 ); // set to input
    P2REN = BIT3 | BIT4 ;     // enable pullup/down resistors
    P2OUT = BIT3 | BIT4 ;     // set resistors to pull up

    /* Uncomment the following code if you want to use interrupts to detect button presses */
    P2IES = BIT3 | BIT4; // listen for high to low transitions
    P2IFG &=  ~(BIT3 | BIT4);
    P2IE = BIT3 | BIT4; // enable interrupts for these pins
}

/**
 * dc: data is 1; command is 0
 * spiBytes: the spi bytes we want to send
 * num_bytes: number of bytes in spiBytes
 */
void sendBytes(uint8_t dc, uint8_t *spiBytes, int num_bytes){
    P1OUT &= ~BIT6; // chip select low
    //Turn on Data or command;
    if (dc) P2OUT  |= (BIT5);
    else P2OUT  &= ~(BIT5);
    int byte1;
    for (byte1=0;byte1<num_bytes;byte1++){//send 32 bit frame in 8 bit chunks
        while (!(IFG2 & UCB0TXIFG));  // USCI_A0 TX buffer ready?
        UCB0TXBUF=spiBytes[byte1];
    }
    //Turn off Data or command;
    while(UCB0STAT & UCBUSY);
    if (dc) P2OUT  &= ~(BIT5);
        else  P2OUT  |= (BIT5);
    P1OUT |= BIT6; // chip select high
}
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

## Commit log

2022-04-11 added PCB files
    [final.brd, final.sch, final2.brd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]
2022-04-11 added CAM files for final1
    [SNBottom.GBL, SNTop.GTL]
2022-04-15 reads address 0x0E, basically steps! with a catch
    Can read pedo_stp_L (0x0E), the issue is that when it you would want to read pedo_stp_L (0x0F), you for some reason will always read zero when you read pedo_stp_L???? For the pedometer, the code for some reason cannot handle reading more than one address???????? Even when you want to read another address the MSP430 doesn't recognize it?? But the MISO line does output expected values when reading, thus I am certain its a MSP430 issue!
    [main.c]
2022-04-18 2nd pcb files
    [finalPCB2.sch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]
2022-04-25 FINAL PCB files
    [pcb2.GBL, pcb2.GTL]
2022-05-04 FINAL PCB - Schematic and Board files
    [pcb2-1.brd, pcb2-1.sch]

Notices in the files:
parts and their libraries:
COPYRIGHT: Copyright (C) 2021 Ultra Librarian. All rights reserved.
